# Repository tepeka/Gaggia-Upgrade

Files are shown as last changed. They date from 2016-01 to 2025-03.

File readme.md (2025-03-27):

# Gaggia Upgrade

## Features

- PID Temp Control
- Watertank LED with Temp-Ready-Indicator
- Grouphead LED

## BOM

- (Arudino) Nano Atmega328 CH340 [amazon.de](https://www.amazon.de/dp/B0D8WK1MGM?ref=ppx_yo2ov_dt_b_fed_asin_title&th=1)
- 2x Transistor BC547A TO-92 [conrad.at](https://www.conrad.at/de/p/tru-components-transistor-bjt-diskret-tc-bc547a-to-92-anzahl-kanaele-1-npn-1581825.html)
- 12V DC Power Supply
- 5V Step-Down
- Solid State Relais
- Thermocuple
- RCD
- Poti
- 0.96 OLED Display
- LED-Strip 5V Warm White (Group Head)
- LED-Strip 5V Cold White (Water Tank)

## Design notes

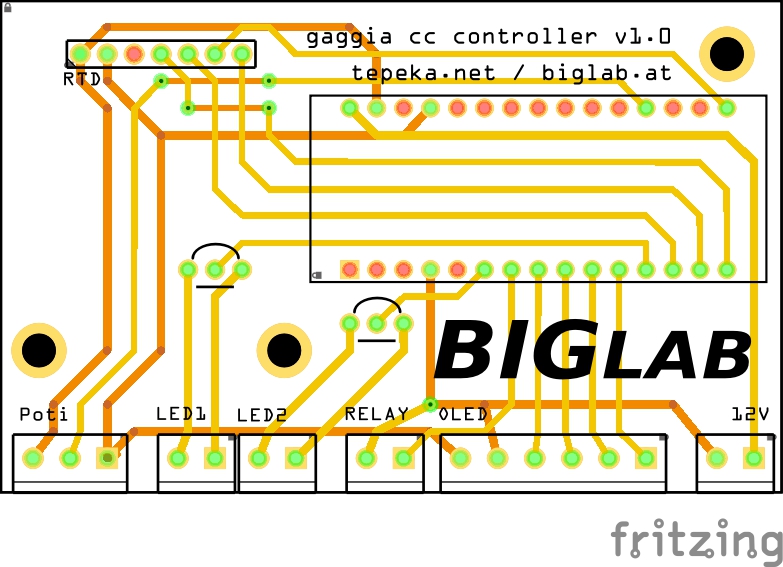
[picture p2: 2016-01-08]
pcb/v1/gaggia_Leiterplatte.jpg

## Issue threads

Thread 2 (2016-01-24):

Create a way to turn heater completely off (e.g. when Poti is set to 0).

tepeka, 2016-01-24:
This feature is needed for descaling.
Because of Gaggia CC's Alu-Boilder descaling with no heat is necessary. If the barista can turn the heater off he can create a constant circular flow by letting the pump suck up the same water which comes out of the brewing unit.

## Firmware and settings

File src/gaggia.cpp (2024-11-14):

#include <Arduino.h>

#include <SPI.h>
#include <Wire.h>

#include "libs/Adafruit_GFX/Adafruit_GFX.h"
#include "libs/Adafruit_SSD1306/Adafruit_SSD1306.h"
#include "libs/MemoryFree/MemoryFree.h"
#include "libs/PID_v1/PID_v1.h"
#include "libs/PlayingWithFusion_MAX31865/PlayingWithFusion_MAX31865.h"

#include "Light.h"
#include "RTD.h"
#include "GaggiaPID.h"
#include "Poti.h"

#if (SSD1306_LCDHEIGHT != 64)
#error("Display height incorrect, please fix Adafruit_SSD1306.h!");
#endif

// -- pins
#define OLED_RESET -1
#define POTI_ANA_PIN A0
#define LED1_PWM_PIN 3
#define RELAY_DIG_PIN 4
#define OLED_CLK 5
#define OLED_MOSI 6
#define OLED_CS 7
#define OLED_DC 8
#define LED2_PWM_PIN 9
#define RTD_SS_PIN 10
// PIN 11/12/13: SPI (RTD)

static const unsigned char PROGMEM GAGGIA_PIC[] = {
    0x00, 0x00, 0x00, 0x00, 0x00, 0x00, 0x00, 0x08, 0x00, 0x00, 0x00, 0x00, 0x00, 0x00, 0x00, 0x00,
    0x00, 0x00, 0x00, 0x01, 0x00, 0x00, 0x00, 0x08, 0x00, 0x00, 0x00, 0x01, 0x00, 0x00, 0x00, 0x00,
    0x00, 0x00, 0x00, 0x01, 0x00, 0x00, 0x00, 0x08, 0x00, 0x00, 0x00, 0x01, 0x00, 0x00, 0x00, 0x00,
    0x00, 0x00, 0x00, 0x03, 0xC3, 0x8B, 0x83, 0x88, 0x8F, 0x01, 0x70, 0x73, 0xC0, 0x00, 0x00, 0x00,
    0x00, 0x00, 0x00, 0x01, 0x04, 0xCC, 0x84, 0xC9, 0x11, 0x81, 0x88, 0x99, 0x00, 0x00, 0x00, 0x00,
    0x00, 0x00, 0x00, 0x01, 0x08, 0x48, 0x48, 0x4A, 0x00, 0x81, 0x09, 0x09, 0x00, 0x00, 0x00, 0x00,
    0x00, 0x00, 0x00, 0x01, 0x0F, 0xC8, 0x4F, 0xCE, 0x0F, 0x81, 0x09, 0xF9, 0x00, 0x00, 0x00, 0x00,
    0x00, 0x00, 0x00, 0x01, 0x08, 0x08, 0x48, 0x0A, 0x10, 0x81, 0x09, 0x01, 0x00, 0x00, 0x00, 0x00,
    0x00, 0x00, 0x00, 0x01, 0x04, 0x4C, 0xC4, 0x49, 0x11, 0x91, 0x08, 0x89, 0x00, 0x00, 0x00, 0x00,
    0x00, 0x00, 0x00, 0x00, 0xC3, 0x8B, 0x83, 0x88, 0x8E, 0x91, 0x08, 0x70, 0xC0, 0x00, 0x00, 0x00,
    0x00, 0x00, 0x00, 0x00, 0x00, 0x08, 0x00, 0x00, 0x00, 0x00, 0x00, 0x00, 0x00, 0x00, 0x00, 0x00,
    0x00, 0x00, 0x00, 0x00, 0x00, 0x08, 0x00, 0x00, 0x00, 0x00, 0x00, 0x00, 0x00, 0x00, 0x00, 0x00,
    0x00, 0x00, 0x00, 0x00, 0x00, 0x08, 0x00, 0x00, 0x00, 0x00, 0x00, 0x00, 0x00, 0x00, 0x00, 0x00,
    0x00, 0x00, 0x00, 0x00, 0x00, 0x00, 0x00, 0x00, 0x00, 0x00, 0x00, 0x00, 0x00, 0x00, 0x00, 0x00,
    0x00, 0x00, 0x00, 0x00, 0x00, 0x00, 0x00, 0x00, 0x00, 0x00, 0x00, 0x00, 0x00, 0x00, 0x00, 0x00,
    0x00, 0x00, 0x00, 0x00, 0x00, 0x00, 0x00, 0x00, 0x00, 0x00, 0x00, 0x00, 0x00, 0x00, 0x00, 0x00,
    0x00, 0x00, 0x00, 0x00, 0x00, 0x00, 0x00, 0x00, 0x00, 0x00, 0x00, 0x00, 0x00, 0x00, 0x00, 0x00,
    0x00, 0x00, 0x00, 0x00, 0x00, 0x00, 0x00, 0x00, 0x00, 0x00, 0x00, 0x00, 0x00, 0x00, 0x00, 0x00,
    0x00, 0x00, 0x00, 0x00, 0x00, 0x00, 0x00, 0x00, 0x00, 0x00, 0x00, 0x00, 0x00, 0x00, 0x00, 0x00,
    0x00, 0x00, 0x00, 0x00, 0x00, 0x00, 0x00, 0x00, 0x00, 0x00, 0x00, 0x00, 0x00, 0x00, 0x00, 0x00,
    0x00, 0x00, 0x00, 0x00, 0x00, 0x00, 0x00, 0x00, 0x00, 0x00, 0x00, 0x00, 0x00, 0x00, 0x00, 0x00,
    0x00, 0x00, 0x00, 0x00, 0x00, 0x00, 0x00, 0x00, 0x00, 0x00, 0x00, 0x00, 0x00, 0x00, 0x00, 0x00,
    0x00, 0x00, 0x00, 0x00, 0x00, 0x00, 0x00, 0x00, 0x00, 0x00, 0x00, 0x00, 0x00, 0x00, 0x00, 0x00,
    0x00, 0x00, 0x00, 0x00, 0x00, 0x00, 0x00, 0x00, 0x00, 0x00, 0x00, 0x00, 0x00, 0x00, 0x00, 0x00,
    0x00, 0x00, 0x00, 0x00, 0x00, 0x00, 0x00, 0x00, 0x00, 0x00, 0x00, 0x00, 0x00, 0x00, 0x00, 0x00,
    0x00, 0x1F, 0xFE, 0x00, 0x7F, 0x00, 0x00, 0xFF, 0xF0, 0x01, 0xFF, 0xE7, 0xF0, 0x07, 0xF0, 0xF0,
    0x00, 0x7F, 0xFE, 0x00, 0x7F, 0x00, 0x03, 0xFF, 0xF0, 0x07, 0xFF, 0xE7, 0xF0, 0x07, 0xF8, 0xF0,
    0x00, 0xFF, 0xFE, 0x00, 0xFF, 0x80, 0x0F, 0xFF, 0xF0, 0x1F, 0xFF, 0xE7, 0xF0, 0x07, 0xF8, 0xF0,
    0x03, 0xFF, 0xFE, 0x00, 0xFF, 0x80, 0x1F, 0xFF, 0xF0, 0x3F, 0xFF, 0xE7, 0xF0, 0x0F, 0xF8, 0xF0,
    0x07, 0xFF, 0xFE, 0x00, 0xFF, 0x80, 0x3F, 0xFF, 0xF0, 0x7F, 0xFF, 0xE7, 0xF0, 0x0F, 0xF8, 0x60,
    0x07, 0xFF, 0xFE, 0x00, 0xFF, 0x80, 0x7F, 0xFF, 0xF0, 0xFF, 0xFF, 0xE7, 0xF0, 0x0F, 0xFC, 0x00,
    0x0F, 0xFE, 0x00, 0x01, 0xFF, 0xC0, 0xFF, 0xE0, 0x00, 0xFF, 0xE0, 0x07, 0xF0, 0x0F, 0xFC, 0x00,
    0x1F, 0xF0, 0x00, 0x01, 0xFF, 0xC0, 0xFF, 0x80, 0x01, 0xFF, 0x00, 0x07, 0xF0, 0x1F, 0xFC, 0x00,
    0x1F, 0xE0, 0x00, 0x01, 0xFF, 0xC1, 0xFE, 0x00, 0x03, 0xFE, 0x00, 0x07, 0xF0, 0x1F, 0xFC, 0x00,
    0x3F, 0xC0, 0x00, 0x01, 0xFF, 0xE1, 0xFC, 0x00, 0x03, 0xFC, 0x00, 0x07, 0xF0, 0x1F, 0xFE, 0x00,
    0x3F, 0x80, 0x00, 0x03, 0xFF, 0xE3, 0xFC, 0x00, 0x03, 0xF8, 0x00, 0x07, 0xF0, 0x1F, 0xFE, 0x00,
    0x3F, 0x80, 0x00, 0x03, 0xFF, 0xE3, 0xF8, 0x00, 0x07, 0xF0, 0x00, 0x07, 0xF0, 0x3F, 0xFE, 0x00,
    0x7F, 0x00, 0x00, 0x03, 0xFF, 0xE3, 0xF8, 0x00, 0x07, 0xF0, 0x00, 0x07, 0xF0, 0x3F, 0xFF, 0x00,
    0x7F, 0x00, 0x00, 0x03, 0xFF, 0xF3, 0xF8, 0x00, 0x07, 0xF0, 0x00, 0x07, 0xF0, 0x3F, 0xFF, 0x00,
    0x7F, 0x00, 0x00, 0x07, 0xFF, 0xF3, 0xF0, 0x00, 0x07, 0xF0, 0x00, 0x07, 0xF0, 0x3F, 0xFF, 0x00,
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

const short LED_HANDLING_INTERVAL = 20;
const short TEMP_READ_INTERVAL = 50;
const short PID_CALC_INTERVAL = 10;
const short PLOT_INTERVAL = 750;

unsigned long lastLedHandling = 0;
unsigned long lastTempRead = 0;
unsigned long lastPidCalc = 0;
unsigned long lastPlot = 0;


// -- rtd & temp
const short INVALID_TEMP = -274; // °C
const short TEMP_MEM_SIZE = 10;
const short TEMP_THRESHOLD = 1; // °C
RTD rtd(RTD_SS_PIN);
double tempMem[TEMP_MEM_SIZE];
short tempMemIdx = 0;
double tempMemSum = 0;
double tempMemAvg = 0;

// -- led
Light light1(LED1_PWM_PIN);
Light light2(LED2_PWM_PIN);

// -- pid
const short SETPOINT_MIN = 100; // °C
const short SETPOINT_MAX = 120; // °C
const short SETPOINT_INIT = 110; // °C
const unsigned long SAMPLE_TIME = 500;
const double WINDOW_SIZE = 1000;
const double P = 60;
const double I = 1.2;
const double D = 10;
GaggiaPID pid(SETPOINT_INIT, P, I, D, SAMPLE_TIME, WINDOW_SIZE);

// -- poti
Poti poti(POTI_ANA_PIN, SETPOINT_MIN, SETPOINT_MAX);

// -- display
Adafruit_SSD1306 display(OLED_MOSI, OLED_CLK, OLED_DC, OLED_RESET, OLED_CS);

void doInit();
void doLedHandling();
void doReadTemp();
void doCalcPid();
void doPlot();

void setup()
{
  Serial.begin(9600);
  doInit();
}

void loop()
{
  unsigned long now = millis();
  // -- execute led pulse
  if (now - lastLedHandling > LED_HANDLING_INTERVAL)
  {
    doLedHandling();
    lastLedHandling = now;
  }
  // -- execute read temp
  if (now - lastTempRead > TEMP_READ_INTERVAL)
  {
    doReadTemp();
    lastTempRead = now;
  }
  // -- execute pid calc
  if (now - lastPidCalc > PID_CALC_INTERVAL)
  {
    doCalcPid();
    lastPidCalc = now;
  }
  // -- execute send http
  if (now - lastPlot > PLOT_INTERVAL)
  {
    doPlot();
    lastPlot = now;
  }
}

void doInit()
{
  light1.On(100);
  tempMem[0] = INVALID_TEMP;
  pinMode(RELAY_DIG_PIN, OUTPUT);
  display.begin(SSD1306_SWITCHCAPVCC);
  display.clearDisplay();
  display.drawBitmap(0, 0, GAGGIA_PIC, 128, 64, 1);
  display.display();
  delay(5000);
  display.clearDisplay();
}

void doLedHandling()
{
  light1.HandlePulse();
  light2.HandlePulse();
}

void doReadTemp()
{
  // -- calc avg temp
  double temp = rtd.ReadTemp();
  if (tempMem[0] == INVALID_TEMP)
  {
    // initialize
    for (short i = 0; i < TEMP_MEM_SIZE; i++)
    {
      tempMem[i] = tempMemAvg = temp;
      tempMemSum += temp;
    }
  }
  else
  {
    tempMemSum -= tempMem[tempMemIdx];
    tempMem[tempMemIdx] = temp;
    tempMemSum += tempMem[tempMemIdx];
    tempMemIdx = (tempMemIdx + 1) % TEMP_MEM_SIZE;
    tempMemAvg = tempMemSum / TEMP_MEM_SIZE;
  }
  // -- set led state depending on temp
  if (SETPOINT_MIN == pid.GetSetpoint())
    light2.On(75);
  else if (tempMemAvg < pid.GetSetpoint() - TEMP_THRESHOLD)
    light2.PulseOn(75);
  else if (tempMemAvg > pid.GetSetpoint() + TEMP_THRESHOLD)
    light2.PulseOn(75);
  else
    light2.On(75);
}

void doCalcPid()
{
  short setpoint = poti.GetValue();
  pid.UpdateSetpoint((double)setpoint);
  bool on = pid.Calculate(tempMemAvg);
  if (on)
  {
    digitalWrite(RELAY_DIG_PIN, HIGH);
  }
  else
  {
    digitalWrite(RELAY_DIG_PIN, LOW);
  }
  display.clearDisplay();
  display.setTextSize(1);
  display.setTextColor(WHITE);
  display.setCursor(0, 0);
  display.print(F("Temperature: "));
  display.println(String(tempMemAvg));
  display.print(F("Setpoint:    "));
  display.println(String(setpoint));
  display.print(F("Heat:        "));
  display.print(String(pid.GetHeatPercentage()));
  display.println("%");
  display.print(F("Mem:         "));
  display.println(String(freeMemory()));
  display.display();
}

void doPlot()
{
  short setpoint = poti.GetValue();
  // Serial.print(F("msg0,"));
  Serial.print(String(tempMemAvg));
  Serial.print(F(","));
  Serial.print(setpoint);
  Serial.print(F(","));
  Serial.print(setpoint + TEMP_THRESHOLD);
  Serial.print(F(","));
  Serial.print(setpoint - TEMP_THRESHOLD);
  Serial.println();
}

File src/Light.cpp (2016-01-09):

#include "Light.h"

Light::Light(short pin) {
  m_pin = pin;
  pinMode(m_pin, OUTPUT);
}

Light::~Light() { }

void Light::On() {
  On(100);
}

void Light::On(short dim) {
  m_pulse_val = m_dim_val = map(dim, 0, 100, 0, 255);
  m_pulse = false;
  m_pulse_up = false;
  analogWrite(m_pin, m_dim_val);
}

void Light::Off() {
  m_pulse_val = m_dim_val = 0;
  m_pulse = false;
  m_pulse_up = true;
  analogWrite(m_pin, m_dim_val);
}

void Light::PulseOn() {
  PulseOn(m_dim_val);
}

void Light::PulseOn(short dim) {
  if (!m_pulse) {
    m_pulse = true;
    m_dim_val = dim;
  }
}

void Light::HandlePulse() {
  if (m_pulse) {
    if (m_pulse_up) {
      m_pulse_val += 10;
    } else {
      m_pulse_val -= 10;
    }
    if (m_pulse_val > m_dim_val) {
      m_pulse_val = m_dim_val;
      m_pulse_up = false;
    }
    if (m_pulse_val < 0) {
      m_pulse_val = 0;
      m_pulse_up = true;
    }
    analogWrite(m_pin, m_pulse_val);
  }
}

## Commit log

2015-05-02 encapsulate pid
2015-08-08 fix pins (for nano)
    [RTD.cpp]
2015-08-18 12V upgrade
2016-01-08 restructure project files add platine layout add display image
    [gaggia-0.1.fzz, gaggia.fzz, gaggia_fail1.fzz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]
2016-01-08 tune pid values
2016-01-09 undo pid lib changes improve light handling
2016-01-14 Bugfixe, PID adjustments
2016-03-16 improve pid (new sensor)
2025-03-27 restructure folders
    [gaggia-0.1.fzz, gaggia.fzz, gaggia_fail1.fzz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]
2025-03-27 upgrade board
